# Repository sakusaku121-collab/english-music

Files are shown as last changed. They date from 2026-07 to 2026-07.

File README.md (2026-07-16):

# left-hand-controller

マウスと併用する左手ゲーミングデバイスの自作プロジェクト。
アナログスティック(ホールセンサー)+ メカニカルボタンで、WASD移動をアナログスティックに置き換える。

市販品(Mouserpad v2 等)との差別化ポイント:

- **ダッシュ(Shift)は独立した物理ボタン** — スティックをどれだけ倒してもダッシュは発動しない。
  回復アイテム使用中のレレレ移動・前進でスプリントが暴発してキャンセルされる問題を設計レベルで排除
- **コンテキスト抑制** — 回復キーを押した直後の数秒間はオートダッシュを無効化(オートダッシュをオンにした場合のみ)
- **プロファイル切替** — ゲームごとのキーマップ+スティック挙動を本体フラッシュに保存。どのPCに挿しても同じ挙動
- **筐体はパラメトリック設計** — グリップ角度・ボタン位置を数値で調整して自分の手に合わせられる

## 構成

```
firmware/   Raspberry Pi Pico 用ファームウェア (CircuitPython)
  code.py     メインループ
  config.py   キーマップ・スティック挙動・プロファイル定義(編集するのは基本ここだけ)
hardware/   筐体・部品
  case.scad   パラメトリック筐体モデル (OpenSCAD)
  BOM.md      部品表
docs/
  design-notes.md   設計判断の記録(なぜこの仕様なのか)
```

## 必要なもの

| 部品 | 目安価格 | 備考 |
|---|---|---|
| Raspberry Pi Pico | ~800円 | 無印(有線)。売る前提なので無線モデルは使わない |
| ホールセンサー式スティックモジュール | 500〜1,000円 | PS4/Switch互換の補修部品。アンチドリフト |
| タクトスイッチ or メカニカルスイッチ ×14 | 500〜2,000円 | Kailh choc 推奨(薄型・打鍵感) |
| 配線・M3インサート・ネジ | ~500円 | |
| フィラメント | 試作PLA / 販売版PETG or ASA | 1台あたり100〜150g |

詳細は [hardware/BOM.md](hardware/BOM.md) を参照。

## ファームウェアのセットアップ

1. Pico に [CircuitPython](https://circuitpython.org/board/raspberry_pi_pico/) の UF2 を書き込む
   (BOOTSEL を押しながらUSB接続 → 現れたドライブに UF2 をドラッグ)
2. [Adafruit CircuitPython Bundle](https://circuitpython.org/libraries) から
   `adafruit_hid` フォルダを `CIRCUITPY/lib/` にコピー
3. `firmware/code.py` と `firmware/config.py` を `CIRCUITPY/` 直下にコピー
4. 挿し直すとUSBキーボードとして認識される

## 配線

| 信号 | Picoピン | 備考 |
|---|---|---|
| スティック X軸 | GP26 (ADC0) | |
| スティック Y軸 | GP27 (ADC1) | |
| スティック押し込み | GP11 | C キー |
| 天面ボタン 1/2/3/4 | GP2/GP3/GP4/GP5 | |
| 天面ボタン Q/E/X/F/Tab | GP6/GP7/GP8/GP9/GP10 | |
| 側面ボタン G/Space/Ctrl | GP12/GP13/GP14 | |
| **ダッシュボタン (Shift)** | GP15 | 本プロジェクトの目玉 |
| **ESCボタン** | GP16 | 市販品最大の不満点への対策 |
| 予備ボタン ×2 | GP17/GP18 | 位置・割当は試作で決定 |

ボタンは片側GND、反対側を各GPIOへ(内部プルアップ使用)。
スティックモジュールは VCC→3V3、GND→GND。

USBはPicoのmicroBを直接筐体面に出さず、**パネルマウントUSB-C延長ケーブル**を介して
筐体に固定する(市販品はコネクタ直付け+面一設置が原因で3.5ヶ月破損の報告あり)。

## プロファイル切替

`Tab + スティック押し込み` を1.5秒長押しで次のプロファイルへ切替(選択はフラッシュに保存)。
プロファイルの中身は `firmware/config.py` の `PROFILES` を編集。

## ライセンス

MIT(販売を見据えてクリーンに保つ。外部GPLコードは取り込まない方針)

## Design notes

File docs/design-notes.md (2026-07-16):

# 設計ノート — なぜこの仕様なのか

## 発端

市販の左手デバイス(Mouserpad v2、¥7,590)を検討したが、実際のプレイで致命的な問題があった:

1. **レレレ中のダッシュ暴発**
   Apex のホライゾンで、グラビティリフトで浮きながらバッテリーを巻き、
   弾避けに左右移動(レレレ)を混ぜると、スティックが前方向を含んだ瞬間に
   オートダッシュ(Shift)が乗って回復がキャンセルされる。
2. **前進しながらの回復も不可**
   回復しつつ前に進みたいとき、スティックを倒しすぎるとオートダッシュが
   発動して同じくキャンセル。つまり「回復中はスティックを慎重に倒す」
   ことをプレイヤー側が強いられる。

市販品はこの挙動を変更できない。→ 自作すれば設計レベルで直せる。

## 主要な設計判断

### D1. ダッシュは独立した物理ボタン(デフォルト)

- スティック入力とスプリントを完全に分離する。
  スティックをどれだけ・どの方向に倒しても Shift は乗らない。
- 誤爆源を「賢い制御で抑える」のではなく「構造的に消す」。
  デバッグが楽で、挙動が予測可能。

### D2. オートダッシュはオプションとして残す(比較・他ゲー用)

- プロファイル `auto-dash` で有効化できる。
- ただし市販品との差別化として:
  - **発動閾値を高めに設定可能**(threshold 0.92〜)
  - **コンテキスト抑制**: 回復キー(4)を押した直後 N 秒間は
    オートダッシュを無効化。バッテ5秒/医療キット8秒に合わせて調整。

### D3. プロファイルは本体フラッシュに保存

- `microcontroller.nvm` に選択中インデックスを保存。
- どの PC に挿しても同じ挙動。ドライバ・常駐ソフト不要
  (= 販売時のサポートコストが低い)。

### D4. 有線 USB 固定

- 無線化すると技適(電波法)が必要で個人販売には非現実的。
- 有線 USB バスパワーなら PSE(電気用品安全法)も対象外。

### D5. ファームウェアは完全自作(CircuitPython)

- GPL 系の既製ファームウェアを流用するとソース公開義務が絡む。
  販売を見据えて MIT でクリーンに保つ。
- 挙動の芯(8方向判定、ヒステリシス、抑制ロジック)は 200 行程度で書ける。

### D6. 筐体はオリジナル形状

- Mouserpad v2 の形状をそのまま複製して販売すると
  不正競争防止法(形態模倣、発売から3年)に触れるおそれ。
- どのみち自分の手に合わせてグリップを再設計するので、
  パラメトリックモデル(case.scad)で角度・配置を数値管理する。

## 市販品(Mouserpad v2)レビュー分析 — 弱点と本機での対策

2026-07 時点の Amazon レビューから抽出。★4.1(47件)でもこれだけ不満が残っている
= 改善版を出せば刺さる余地が大きい。

| # | 市販品の弱点(レビューより) | 本機での対策 |
|---|---|---|
| 1 | **ESCキーが無い**。ゲーム内で再割当できず、ゲーム中はPowerToys等も無効。頻繁にキーボードへ手を伸ばす羽目に | **ESC物理ボタンを追加**(config で `top_esc` として定義済み)。キーマップ自由なので任意キーにも変更可 |
| 2 | **キー割当が固定**(変更不可)。左Shift や ESC が割当できずゲームによっては使い物にならない | ファームウェアの config でフルリマップ可能。プロファイル切替も対応済み |
| 3 | **ボタンの押下感がふんわり**、カチッと感なし。強く押さないと反応せず、二度押しでしのぐ人も。分解したら半田不良の個体もあり | メカニカルスイッチ(Kailh choc 等)+ちゃんとした半田付け。試作段階から導通チェックを工程に入れる |
| 4 | **ボタン数が足りない**(押しにくい位置でもいいから3つ増やして欲しいという要望) | 予備ボタン2個分のピンを config に確保(`spare_1`/`spare_2`)。筐体側で増設位置を試作しながら決める |
| 5 | **小指・薬指が窮屈**。ボタン操作しない指で握り続けるため手首の筋が痛む。「親指側を細く、薬指小指側を太く」という具体的提案あり | `case.scad` のグリップを上下で太さ可変に(親指側細め・下側太め)。パラメトリックなので試作で追い込める |
| 6 | **机の手前端で使うと手が浮いて小指側の掌に荷重集中**、痛み・痺れ。ジェルクッションが欲しいという声 | パームレスト部を広めに設計+底面にゲルパッド貼付を標準化。設置姿勢(机上前提)をドキュメント化 |
| 7 | **正面最下段の1・2ボタンが握りを浮かせないと届かない**=ほぼ死にボタン | ボタン配置は`button_layout`で座標管理。届かない位置には置かない。試作で親指可動域を実測してから確定 |
| 8 | **スティックがシビア**。少し倒しただけで全開扱い、歩ける範囲が1mm程度。乗り物操縦では曲がりすぎる。オートダッシュ常時発動で余計に酷い | デッドゾーン・発動閾値を config で調整可能。オートダッシュはデフォルトOFF+コンテキスト抑制。将来的にはゲームパッド軸出力プロファイルも検討(ロードマップ参照) |
| 9 | **MicroUSBコネクタが3.5ヶ月で破損**(役立った47人=最重要レビュー)。基板を筐体と面一に置いたせいでコネクタ金属部が露出し、奥まで挿そうとグリグリやって壊れる | **コネクタを筐体内に沈めない設計ミスを回避**: Pico本体は内部固定し、パネルマウントUSB-C延長ケーブルで筐体面に出す。ストレインリリーフ付き。修理性も上がる |
| 10 | **スティックの首回り強度が弱い**、2週間で擦れ粉 | ホールセンサー式の交換モジュール前提。開口部エッジを面取りし、モジュール交換をネジ止め式に |
| 11 | 背面の交換パーツが付属するが**説明書に一切記載なし** | 説明書(README)に全付属品と用途を明記。販売時はここが信頼の差になる |

レビュー全体の温度感: 「コンセプトは唯一無二、品質は値段なり、改善版を出してくれ」。
つまり**市場は改善版を待っている**。AZERON Cyborg(高価格帯)との間に価格帯の空白もある。

## 販売までのロードマップ

1. **自分用1号機**: PLA試作でグリップ形状を確定 → PETG で常用機
2. **公開**: SNS で反応を見る(写真+ダッシュ分離のデモ動画)
3. **販売版設計**: QC しやすい分割、キーキャップ色替えでカラバリ、
   Raspberry Pi 財団の VID/PID 割当を申請
4. **販路**: BOOTH から開始 → 反応次第で Makuake 等のクラファン

## 未解決・要検証

- [ ] スティックモジュールの ADC 実効レンジ実測(HALF_RANGE の補正)
- [ ] グリップ角度の最適値(grip_angle 24/28/32° で試作予定)
- [ ] Kailh choc 化した場合の天面プレート厚と穴形状
- [ ] 回復キー抑制のデフォルト秒数(バッテ運用なら 5.5s が適正かも)
- [ ] USB ポーリングレートの実測(CircuitPython の HID は実測で確認する)
- [ ] ゲームパッド軸出力プロファイル(乗り物操縦対策。キーボード8方向では原理的に
      アナログ操作にならないため、XInput/DirectInput 軸として出すモードを検討)
- [ ] パネルマウント USB-C 延長ケーブルの選定(レビュー#9 のコネクタ破損対策)
- [ ] spare_1 / spare_2 の実装位置(押しにくくてもいいから欲しい、というレビュー要望)

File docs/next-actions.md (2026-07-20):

# ネクストアクション

進捗はチェックボックスで管理。詳細な理由は design-notes.md、価格の目安は shopping-list.md 参照。

> **状況 (2026-07-19)**: プリンター+フィラメント到着済み(前倒し)。初期セットアップ中。
> グリップ試作STL(24/28/32°)は `hardware/stl/` に生成済み。
> **フェーズ1電子部品と収納・工具はまだ未発注 ← 最優先。**

## ✅ 済み

- [x] プリンター選定・購入(A1 mini ¥26,000 セール)
- [x] フィラメント購入(PLA黒・PETG黒 各1kg スプール付き)+予備ホットエンド
- [x] ファームウェア骨格・筐体パラメトリックモデル・競合レビュー分析
- [x] グリップ試作STL生成(24°/28°/32°)

## 🔄 いま

- [ ] **1. A1 mini 初期セットアップ**(30〜45分)
      保護材外し → ウィザード → 自動キャリブレーション → PLA装填 → サンプル印刷
- [ ] **2. Bambu Studio をPCにインストール** → `grip_test_28deg.stl` を印刷(サポート自動ON)

## 🛒 発注する(未発注・最優先)

### 電子部品

| 品名 | おすすめ購入先 | 備考 |
|---|---|---|
| Raspberry Pi Pico(無印・ピンヘッダ実装済み) | **秋月電子通商**(akizukidenshi.com) | 通販コード検索「Pico H」。〜¥1,000 |
| ホールセンサースティックモジュール ×2 | **Amazon** | 検索「ホールエフェクト ジョイスティック PS4 交換」。「Hall Effect」明記の物のみ |
| タクトスイッチ 6mm ×20 | **秋月電子** | Picoと同時注文で送料節約 |
| ブレッドボード+ジャンパワイヤセット | **秋月電子** or Amazon(ELEGOO等) | |
| 耐熱電子ワイヤ AWG28 | **秋月電子** | |
| 静電気防止袋 | **Amazon** | |

### 工具(持ってなければ)

| 品名 | おすすめ購入先 | 備考 |
|---|---|---|
| はんだごて HAKKO FX-600 | **Amazon** or ヨドバシ | 偽物注意、販売元をよく確認 |
| はんだ・こて台 | 同上 | |
| ニッパー・ワイヤーストリッパー | **Amazon** or ホームセンター | |
| テスター | **Amazon** | 2,000円以下ので十分 |
| デジタルノギス | **Amazon**(シンワ測定が定番) | |

### 収納・管理

| 品名 | おすすめ購入先 | 備考 |
|---|---|---|
| トランク型工具箱(TRUSCO T-350等) | **Amazon** or **モノタロウ** | 内寸35cm以上 |
| 仕切り可動パーツケース ×2(リングスター スーパーピッチ) | **Amazon** or ホームセンター | |
| 耐熱シリコン作業マット | **Amazon** | |
| フィラメント防湿: 6L級密閉容器 ×2+シリカゲル+湿度計 | 容器は**ニトリ/ホームセンター**、乾燥剤・湿度計は**Amazon** | SUNLUドライボックス(Amazon)でも可 |
| M3ヒートインサート・M3×8皿ネジ | **Amazon**(uxcell等) or **モノタロウ** | v1筐体で使用 |

**発注のコツ**: 秋月でまとめて1回+Amazonでまとめて1回の計2注文に集約すると送料と手間が最小。

## ⬜ 印刷とグリップ確定(電子部品なしで進む)

- [ ] **3. grip_test_28deg.stl を印刷** → 握った感想+写真を共有
- [ ] **4. 24°/32°も印刷して比較** → 角度確定
- [ ] **5. 太さ・付け根・天面の微調整版を印刷**(必要なら数回転)
- [ ] **6. 親指可動域を実測 → ボタン配置(button_layout)確定**

## ⬜ 電子部品が届いたら

- [ ] **7. PicoにCircuitPython導入 → ブレッドボード仮組み**
- [ ] **8. ファームウェア書き込み+スティックADC実測合わせ**(Claudeと一緒に)
- [ ] **9. メモ帳とApex射撃訓練場で入力確認**

## ⬜ 形が決まったら

- [ ] **10. v1筐体設計**(内部空洞・基板マウント・底蓋・パネルマウントUSB-C口)
- [ ] **11. はんだ付け本組み → 動作確認**
- [ ] **12. PETGで常用機を印刷して移行**
- [ ] **13. Apex実戦投入 → config煮詰め**(バッテ巻きレレレが快適になったら勝ち)

## ⬜ 売る気になったら

- [ ] **14. SNSに写真+デモ動画投稿 → 反応を見る**
- [ ] **15. 反応があれば販売版設計へ**(design-notes.md のロードマップ参照)

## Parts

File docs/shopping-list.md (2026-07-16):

# 買い物リスト

段階別。フェーズ1はプリンター到着前でも進められる(ブレッドボードでファームウェア検証)。

> **状況 (2026-07-16)**: プリンター本体+フィラメント2巻+予備ホットエンドを注文済(計¥31,498)。
> 発送予定 7/23頃。**到着までにフェーズ1(電子部品)とフェーズ2の残り(ネジ・インサート・防湿箱)を発注しておくこと。**

## フェーズ1: 電子工作(今すぐ買ってOK) — 約6,000〜9,000円

| ✓ | 品名 | 数量 | 目安価格 | 入手先 | メモ |
|---|---|---|---|---|---|
| ☐ | Raspberry Pi Pico(無印) | 1 | 800円 | 秋月電子 / スイッチサイエンス | ピンヘッダ実装済み版が楽(+200円)。**W(無線)ではなく無印** |
| ☐ | ホールセンサー式スティックモジュール | 2 | 1,000〜2,000円 | Amazon「ホールエフェクト ジョイスティック 補修 PS4」 | **予備込みで2個**。押し込みスイッチ付きを選ぶ |
| ☐ | タクトスイッチ 6mm | 20 | 300円 | 秋月電子 | 14個使用+予備 |
| ☐ | ブレッドボード + ジャンパワイヤ(オスオス/オスメス) | 1式 | 800円 | 秋月電子 / Amazon | プリンター到着前のファームウェア検証用 |
| ☐ | 耐熱電子ワイヤ AWG28(数色) | 1式 | 500円 | 秋月電子 | 本組み用 |
| ☐ | USBケーブル microB(データ通信対応) | 1 | 300〜500円 | | **充電専用ケーブル不可**。手持ちがあれば省略 |
| ☐ | はんだごてセット(温調式) | 1 | 2,000〜4,000円 | Amazon(HAKKO FX-600 なら4,000円前後) | 手持ちがあれば省略 |
| ☐ | はんだ(鉛フリー or 共晶 0.8mm) | 1 | 500円 | | |
| ☐ | ニッパー・ワイヤーストリッパー | 1式 | 1,000円 | | 手持ちがあれば省略 |
| ☐ | テスター(導通チェックができれば安物で可) | 1 | 1,000〜2,000円 | | 配線ミス調査に必須。手持ちがあれば省略 |

## 収納・管理(フェーズ1と一緒に買う) — 約4,000〜5,500円

方針: **「工具箱ひとつにプロジェクト全部が入る」状態**にする。小物は仕切りケースに分類し、
その仕切りケースごと大きい工具箱に収まるサイズで選ぶ。

| ✓ | 品名 | 数量 | 目安価格 | 入手先 | メモ |
|---|---|---|---|---|---|
| ☐ | トランク型工具箱(内寸 幅350mm以上) | 1 | 2,000〜3,000円 | TRUSCO トランクツールボックス T-350 / アイリスオーヤマ ハードケース | **これが「全部入る」母艦**。はんだごて・工具・下記の仕切りケース2個が丸ごと入るサイズを確認して買う |
| ☐ | 仕切り可動式パーツケース(小) | 2 | 600〜900円/個 | リングスター スーパーピッチ SP-3000 / SK11 パーツケース | 1個目: スイッチ・スティック・Pico等の電子部品用。2個目: ネジ・インサート・ゴム足等の機構部品用。仕切りが「可動式」のものを選ぶ(固定仕切りは後で必ず困る) |
| ☐ | 静電気防止袋(帯電防止ジップ袋) | 10枚 | 300円 | Amazon | Picoと基板の保管用。パーツケースに入れる前にこれに入れる |
| ☐ | 耐熱シリコン作業マット | 1 | 1,000〜1,500円 | Amazon「はんだ付け 作業マット」 | 机の保護+ネジ小物の迷子防止(縁とポケット付き)。丸めれば工具箱に入る |
| ☐ | はんだごて台 | 1 | 700〜1,000円 | HAKKO 633系 | ごてセットに付属していれば省略。安全に直結するのでケチらない |

## フェーズ2: 3Dプリンター(決心がついたら) — 約38,000〜50,000円

| ✓ | 品名 | 数量 | 目安価格 | メモ |
|---|---|---|---|---|
| ☑ | Bambu Lab A1 mini | 1 | **¥26,000 購入済** | 2026-07-16 Bambu公式周年セールで注文。発送予定 7/23頃 |
| ☑ | PLA フィラメント(試作用) | 1kg | **¥2,210 購入済** | Bambu PLA ベーシック ブラック(10101)/ スプール付き。次回からリフィルでOK |
| ☑ | PETG フィラメント(常用機) | 1kg | **¥1,885 購入済** | Bambu PETG ベーシック ブラック(30105)/ スプール付き。次回からリフィルでOK |
| ☑ | ホットエンド予備 0.4mm ステンレス | 1 | **¥1,403 購入済** | 同時購入割引で確保。詰まり時の即時交換用 |
| ☐ | M3 ヒートインサート(M3×5×4程度) | 20個 | 500円 | Amazon。底蓋固定用 |
| ☐ | M3×8mm 皿ネジ | 20本 | 300円 | |
| ☐ | ヒートインサート用こて先(M3) | 1 | 1,000円 | あると圧入が真っ直ぐ決まる。無くても可 |
| ☐ | 滑り止めゴム足 | 1袋 | 300円 | |
| ☐ | フィラメント防湿ボックス + 乾燥剤 | 2式 | 1,500〜3,000円 | 密閉クリアボックス(1kgスプールが入る6L級)+ シリカゲル + 湿度計。既製品なら SUNLU ドライボックス。**フィラメントの数だけ必要**(PLA用とPETG用で2つ) |
| ☐ | ノギス(デジタル) | 1 | 1,500〜2,500円 | 筐体の寸法合わせ・スティックモジュール実測に必須。工具箱に入るサイズ |

## フェーズ3: 販売版を作る段階で(まだ買わない)

| ✓ | 品名 | 目安価格 | メモ |
|---|---|---|---|
| ☐ | Kailh choc v1 スイッチ + キーキャップ | 打鍵感の差別化。遊舎工房で試打してから選ぶ | |
| ☐ | ASA フィラメント | 3,000〜4,000円/kg | 耐熱・耐候。販売版筐体用 |
| ☐ | AMS lite(多色ユニット) | 30,000円前後 | ツートン展開したくなったら |
| ☐ | USBケーブル(製品同梱用)まとめ買い | | |
| ☐ | 梱包材(箱・緩衝材) | | BOOTH発送用 |

## 合計目安

- **フェーズ1+収納**(工具持ちなら): 約7,000〜9,500円
- **フェーズ1+収納+2**(工具込みフルセット): 約50,000〜60,000円

収納を先に整えておくと、部品が届いた瞬間から「どこに何があるか分かる」状態で始められる。
あとから買うと、散らかった机を片付けるための出費になる(体験談的にみんなそうなる)。

## 買う前の注意

- スティックモジュールは商品ページに「ホールセンサー」「Hall Effect」と明記があるものを。
  無印の互換スティック(可変抵抗式)はドリフトするので買わない
- Pico は技適の絡みで **Pico W を買わないこと**(無線を使わなくても割高なだけ)
- フィラメントは開封後に吸湿するので、乾燥剤入りの密閉袋かボックスも100均で調達しておくと良い

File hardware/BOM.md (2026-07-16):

# 部品表 (BOM)

試作1台分。価格は2026年時点の目安。

## 電子部品

| # | 部品 | 数量 | 目安価格 | 入手先の例 | 備考 |
|---|---|---|---|---|---|
| 1 | Raspberry Pi Pico(無印・ピンヘッダなし) | 1 | ~800円 | 秋月電子、スイッチサイエンス | 販売を見据えて**有線モデル固定**(無線は技適が必要になる) |
| 2 | ホールセンサー式アナログスティックモジュール | 1 | 500〜1,000円 | Amazon「ホールエフェクト ジョイスティック 補修 PS4」 | アンチドリフトの要。押し込みスイッチ付きを選ぶ |
| 3 | タクトスイッチ(6mm) | 14 | ~300円 | 秋月電子 | 試作用。販売版は Kailh choc v1 等に置換予定 |
| 4 | 耐熱電子ワイヤ AWG28 | 適量 | ~300円 | | |
| 5 | USBケーブル(microB、データ通信対応) | 1 | ~300円 | | Pico 無印は microB |

## 機構部品

| # | 部品 | 数量 | 目安価格 | 備考 |
|---|---|---|---|---|
| 6 | M3 ヒートインサート | 4〜6 | ~200円 | 底蓋固定用 |
| 7 | M3 × 8mm 皿ネジ | 4〜6 | ~100円 | |
| 8 | 滑り止めゴム足 | 4 | ~100円 | |

## フィラメント

| 用途 | 材料 | 使用量目安 |
|---|---|---|
| 試作(形状検討) | PLA | 1回 80〜120g × 反復回数 |
| 完成版・販売版 | PETG または ASA | 100〜150g/台 |

PLA は長時間の握り込みと夏場の温度でクリープ変形するため、常用・販売には使わない。

## 合計目安

電子部品+機構部品で **約2,500〜3,000円/台**(フィラメント除く)。

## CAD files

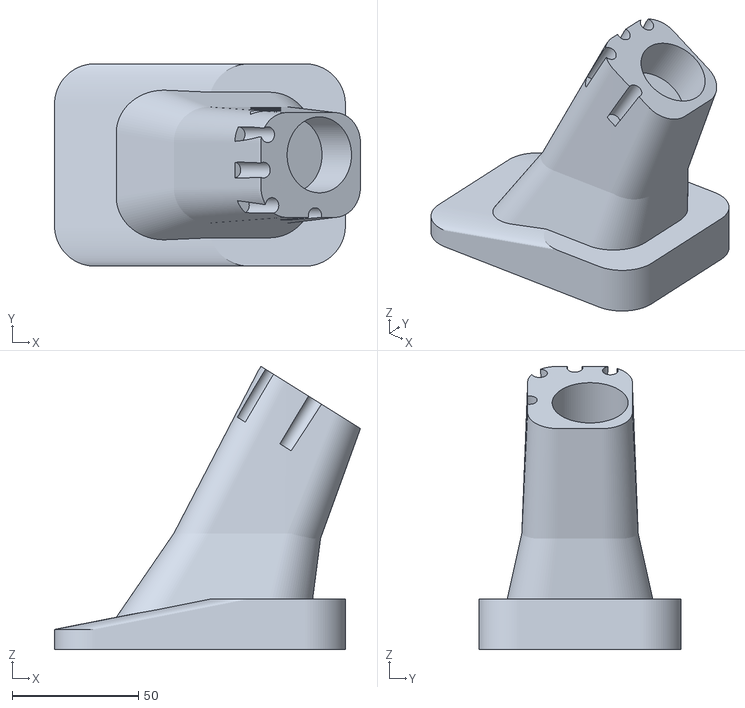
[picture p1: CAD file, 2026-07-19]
hardware/stl/grip_test_24deg.stl
121.0 x 80.0 x 112.0

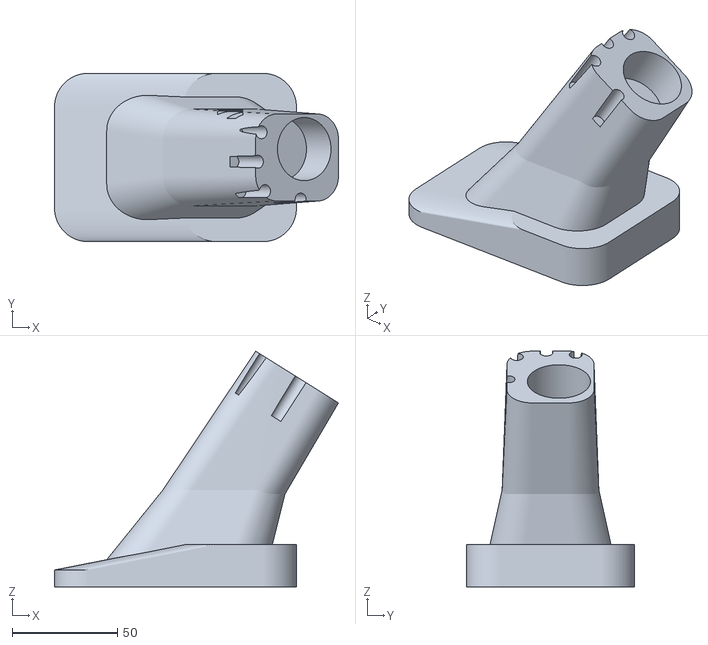
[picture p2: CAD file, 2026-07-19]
hardware/stl/grip_test_32deg.stl
135.0 x 80.0 x 112.0

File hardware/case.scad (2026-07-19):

// =============================================================
// left-hand-controller パラメトリック筐体 v0 (OpenSCAD)
//
// これはエルゴノミクス試作用の「たたき台」。
// 上部のパラメータを変えて印刷 → 握る → 調整、を繰り返す前提。
// 印刷時は $fn を上げる(プレビューは低くて可)。
// =============================================================

// ---- 全体 ----
$fn = 48;            // 曲面分割数(印刷時は 96 以上推奨)
wall = 2.4;          // 壁厚

// ---- ベース(手首を乗せる傾斜土台) ----
// 平板ではなく、手首側が低くグリップ付け根側が高いスロープ。
// 掌の腹をこの斜面で受けて、机の縁での「手が浮く」問題(レビュー#6)も緩和する
base_len          = 115;  // 前後長
base_width        = 80;   // 左右幅
base_height_rear  = 8;    // 手首側の高さ(低い)
base_height_front = 20;   // グリップ付け根側の高さ(高い)

// ---- グリップ(握り柱) ----
grip_angle  = 28;    // 前傾角度(度)。ここが握り心地の最重要パラメータ
grip_height = 78;    // 柱の高さ
grip_width  = 46;    // 柱の左右幅
grip_depth  = 58;    // 柱の前後厚
grip_offset_y = 8;   // ベース上での前後位置(+で高い側=前寄り)
grip_root_h   = 24;  // 付け根ブレンド部の高さ(掌の腹の横が当たる裾広がり)

// ---- 天面ボタンプレート ----
plate_tilt   = 32;   // 天面の傾き(度)。親指が自然に届く角度に合わせる
plate_width  = 52;
plate_length = 72;

// ---- スティック ----
stick_hole_d   = 30;  // スティック可動部の開口径
stick_mount_w  = 34;  // モジュール基板の取付間隔(実測して合わせる)

// ---- ボタン穴 ----
btn_hole = 6.2;       // タクトスイッチキャップ径+クリアランス
                      // Kailh choc なら 13.8x13.8 の角穴に変更する

// ---- 側面ボタン(G / Space / Ctrl) ----
side_btn_w = 12;
side_btn_h = 6;
side_btn_pitch = 16;

// =============================================================

// 天面のボタン配置(プレートローカル座標 [x, y])
// 実機写真を参考にした扇状配置。自分の親指の可動域に合わせて調整する
button_layout = [
    [-16,  26],  // 3
    [ -4,  30],  // 4
    [  8,  26],  // Tab
    [-20,  12],  // F
    [-22,  -2],  // Q
    [-18, -16],  // E
    [  2, -20],  // X
    [-12, -28],  // 1
    [  0, -32],  // 2
];
stick_pos = [4, 4];  // スティック中心(プレートローカル)

module rounded_slab(l, w, h, r) {
    hull()
        for (dx = [-1, 1], dy = [-1, 1])
            translate([dx * (l/2 - r), dy * (w/2 - r), 0])
                cylinder(h = h, r = r);
}

// 手首側の傾斜土台(後端の低い断面と前端の高い断面を hull で繋いだスロープ)
module base() {
    hull() {
        translate([-base_len / 2 + 27, 0, 0])
            rounded_slab(54, base_width, base_height_rear, 16);
        translate([base_len / 2 - 27, 0, 0])
            rounded_slab(54, base_width, base_height_front, 16);
    }
}

// 前傾した握り柱。2段構成:
//  1) 付け根ブレンド: 裾広がりのスカートで土台に滑らかに接続し、
//     掌の腹の横が当たる面を作る
//  2) 握り柱本体: 上端断面は plate_tilt で傾けてあり、
//     hull の天面がそのままボタンプレートになる
module grip() {
    top_shift = grip_height * tan(grip_angle);
    mid_shift = grip_root_h * tan(grip_angle);
    union() {
        hull() {
            translate([grip_offset_y - 4, 0, base_height_front - 12])
                rounded_slab(grip_depth + 20, grip_width + 16, 2, 18);
            translate([grip_offset_y + mid_shift, 0, base_height_front + grip_root_h])
                rounded_slab(grip_depth, grip_width, 2, 14);
        }
        hull() {
            translate([grip_offset_y + mid_shift, 0, base_height_front + grip_root_h])
                rounded_slab(grip_depth, grip_width, 2, 14);
            translate([grip_offset_y + top_shift, 0, base_height_front + grip_height])
                rotate([0, plate_tilt, 0])
                    rounded_slab(grip_depth * 0.8, grip_width * 0.9, 2, 12);
        }
    }
}

// 天面プレートの座標系へ移動(grip() の上端断面と同じ変換)
module on_plate() {
    top_shift = grip_height * tan(grip_angle);
    translate([grip_offset_y + top_shift, 0, base_height_front + grip_height])
        rotate([0, plate_tilt, 0])
            children();
}

// スティック開口+ボタン穴
module top_cutouts() {
    on_plate() {
        translate([stick_pos[0], stick_pos[1], -20])
            cylinder(h = 40, d = stick_hole_d);
        for (p = button_layout)
            translate([p[0], p[1], -20])
                cylinder(h = 40, d = btn_hole);
    }
}

// 側面ボタンの角穴(小指側の面)
module side_cutouts() {
    for (i = [0 : 2])
        translate([grip_offset_y + 12,
                   grip_width / 2 - wall - 2,
                   base_height_front + grip_root_h + 8 + i * side_btn_pitch])
            cube([side_btn_w, wall + 6, side_btn_h]);
}

// ---- 本体 ----
// 現段階はソリッド(軽量化はスライサーのインフィル設定に任せる)。
// 基板・配線用の内部空間と底蓋は、グリップ形状確定後の v1 で設計する
difference() {
    union() {
        base();
        grip();
    }
    top_cutouts();
    side_cutouts();
}

// TODO(v1 以降):
// - 底蓋 + M3インサートボス
// - スティックモジュールの取付ボス(stick_mount_w で位置決め)
// - Kailh choc 用の角穴プレートへの差し替え
// - パネルマウントUSB-C口の開口(レビュー分析#9: 直付け面一コネクタは破損する)
//
// レビュー分析(docs/design-notes.md)からの形状要件:
// - グリップ太さを上下で変える: 親指側(側面ボタン付近)は細く、
//   薬指・小指側(下部)は太く → 握り込む力を減らして手首痛対策 (#5)
// - パームレスト部(base)を広めに取り、掌の小指側エッジに角を当てない (#6)
// - ボタンは親指可動域の実測範囲内のみに配置。届かない位置に置かない (#7)
// - ESC + 予備2ボタンの配置スペースを天面外周に確保 (#1, #4)
// - スティック開口部エッジは面取りし、モジュールはネジ止めで交換可能に (#10)

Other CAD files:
hardware/stl/grip_test_28deg.stl

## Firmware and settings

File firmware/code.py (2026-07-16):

# =============================================================
# left-hand-controller ファームウェア (CircuitPython / Raspberry Pi Pico)
#
# アナログスティック → WASD 8方向キー入力
# ボタン → 任意キー(config.py のプロファイルで定義)
# ダッシュは独立ボタン。オートダッシュはオプション+コンテキスト抑制付き。
# =============================================================
import math
import time

import analogio
import keypad
import microcontroller
import usb_hid
from adafruit_hid.keyboard import Keyboard

import config

# --- 初期化 -------------------------------------------------------
keyboard = Keyboard(usb_hid.devices)

stick_x = analogio.AnalogIn(config.PIN_STICK_X)
stick_y = analogio.AnalogIn(config.PIN_STICK_Y)

button_names = list(config.BUTTON_PINS.keys())
keys = keypad.Keys(
    [config.BUTTON_PINS[n] for n in button_names],
    value_when_pressed=False,  # 内部プルアップ、GNDに落として押下
    pull=True,
)

# 起動時にスティックが中立である前提でセンターを実測
# (組み立て後の個体差・ホールセンサーのオフセットを吸収する)
def read_raw():
    x = stick_x.value
    y = stick_y.value
    return x, y


def calibrate_center(samples=64):
    sx = sy = 0
    for _ in range(samples):
        x, y = read_raw()
        sx += x
        sy += y
        time.sleep(0.002)
    return sx // samples, sy // samples


CENTER_X, CENTER_Y = calibrate_center()
HALF_RANGE = 32768  # 16bit ADC の中心からの振れ幅の目安


def read_stick():
    """スティックの倒し量を (-1.0〜1.0, -1.0〜1.0) で返す。上が +y。"""
    rx, ry = read_raw()
    x = (rx - CENTER_X) / HALF_RANGE
    y = (ry - CENTER_Y) / HALF_RANGE
    if config.STICK_INVERT_X:
        x = -x
    if config.STICK_INVERT_Y:
        y = -y
    # 端で1.0を超えることがあるのでクランプ
    return max(-1.0, min(1.0, x)), max(-1.0, min(1.0, y))


# --- プロファイル管理 ---------------------------------------------
def load_profile_index():
    idx = microcontroller.nvm[0]
    if idx >= len(config.PROFILES):
        idx = 0
    return idx


def save_profile_index(idx):
    microcontroller.nvm[0] = idx


profile_index = load_profile_index()
profile = config.PROFILES[profile_index]


def blink_profile(idx):
    """プロファイル番号を LED の点滅回数で通知(Pico 内蔵LED)。"""
    try:
        import board
        import digitalio

        led = digitalio.DigitalInOut(board.LED)
        led.direction = digitalio.Direction.OUTPUT
        for _ in range(idx + 1):
            led.value = True
            time.sleep(0.12)
            led.value = False
            time.sleep(0.12)
        led.deinit()
    except Exception:
        pass  # LEDが使えない環境でも動作は継続


# --- 8方向セクター定義 --------------------------------------------
# 角度0° = 右、反時計回り。45°ごとの8セクター(境界は22.5°)
SECTOR_KEYS = [
    ("move_right",),
    ("move_right", "move_up"),
    ("move_up",),
    ("move_up", "move_left"),
    ("move_left",),
    ("move_left", "move_down"),
    ("move_down",),
    ("move_down", "move_right"),
]


def stick_direction_keys(x, y, active, cfg):
    """現在押すべき移動キーの論理名 set と、新しい active 状態を返す。

    ヒステリシス: 一度倒したと判定したら、deadzone - release_margin を
    下回るまで解除しない(境界でのチャタリング防止)。
    """
    magnitude = math.sqrt(x * x + y * y)
    press_th = cfg["deadzone"]
    release_th = cfg["deadzone"] - cfg["release_margin"]

    if active:
        if magnitude < release_th:
            return set(), False
    else:
        if magnitude < press_th:
            return set(), False

    angle = math.degrees(math.atan2(y, x))  # -180〜180
    sector = int(((angle + 22.5) % 360) // 45)
    return set(SECTOR_KEYS[sector]), True


# --- メインループ -------------------------------------------------
pressed_buttons = set()      # 押下中の物理ボタン(論理名)
pressed_move_keys = set()    # 押下中の移動キー(論理名)
stick_active = False
auto_dash_on = False
suppress_until = 0.0         # この時刻までオートダッシュ禁止
combo_since = None           # プロファイル切替コンボの押下開始時刻

blink_profile(profile_index)


def set_key(logical_name, pressed):
    """論理名 → 現プロファイルのキーコードで押下/解放。"""
    keycode = profile["keymap"].get(logical_name)
    if keycode is None:
        return
    if pressed:
        keyboard.press(keycode)
    else:
        keyboard.release(keycode)


while True:
    now = time.monotonic()

    # ---- ボタンイベント処理 ----
    event = keys.events.get()
    while event is not None:
        name = button_names[event.key_number]
        if event.pressed:
            pressed_buttons.add(name)
            set_key(name, True)
            # 回復キー等が押されたらオートダッシュを一定時間抑制
            ad = profile["auto_dash"]
            if name in ad["suppress_after"]:
                suppress_until = now + ad["suppress_seconds"]
        else:
            pressed_buttons.discard(name)
            set_key(name, False)
        event = keys.events.get()

    # ---- プロファイル切替コンボ ----
    if all(n in pressed_buttons for n in config.PROFILE_SWITCH_COMBO):
        if combo_since is None:
            combo_since = now
        elif now - combo_since >= config.PROFILE_SWITCH_HOLD_SEC:
            # 全キー解放してからプロファイルを進める
            keyboard.release_all()
            pressed_move_keys = set()
            stick_active = False
            auto_dash_on = False
            profile_index = (profile_index + 1) % len(config.PROFILES)
            profile = config.PROFILES[profile_index]
            save_profile_index(profile_index)
            blink_profile(profile_index)
            combo_since = None
    else:
        combo_since = None

    # ---- スティック → 移動キー ----
    x, y = read_stick()
    want_keys, stick_active = stick_direction_keys(
        x, y, stick_active, profile["stick"]
    )

    for name in want_keys - pressed_move_keys:
        set_key(name, True)
    for name in pressed_move_keys - want_keys:
        set_key(name, False)
    pressed_move_keys = want_keys

    # ---- オートダッシュ(オプション) ----
    ad = profile["auto_dash"]
    if ad["enabled"]:
        magnitude = math.sqrt(x * x + y * y)
        want_dash = (
            magnitude >= ad["threshold"]
            and now >= suppress_until
            and (not ad["forward_only"] or "move_up" in pressed_move_keys)
        )
        if want_dash and not auto_dash_on:
            set_key("dash", True)
            auto_dash_on = True
        elif not want_dash and auto_dash_on:
            # 物理ダッシュボタンを握っている間は離さない
            if "dash" not in pressed_buttons:
                set_key("dash", False)
            auto_dash_on = False

    time.sleep(0.001)  # ~1kHz ポーリング

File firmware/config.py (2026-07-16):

# =============================================================
# left-hand-controller 設定ファイル
# 挙動を変えたいときは基本このファイルだけを編集する。
# =============================================================
import board
from adafruit_hid.keycode import Keycode

# --- ピン割り当て -------------------------------------------------
# スティック(アナログ)
PIN_STICK_X = board.GP26  # ADC0
PIN_STICK_Y = board.GP27  # ADC1

# スティックの向き調整(組み付け方向に合わせて反転)
STICK_INVERT_X = False
STICK_INVERT_Y = True  # 多くのモジュールは上に倒すとADC値が下がる

# ボタン: 論理名 → GPIO
# 論理名はプロファイルのキーマップから参照される
BUTTON_PINS = {
    "top_1": board.GP2,
    "top_2": board.GP3,
    "top_3": board.GP4,
    "top_4": board.GP5,
    "top_q": board.GP6,
    "top_e": board.GP7,
    "top_x": board.GP8,
    "top_f": board.GP9,
    "top_tab": board.GP10,
    "stick_click": board.GP11,
    "side_g": board.GP12,
    "side_space": board.GP13,
    "side_ctrl": board.GP14,
    "dash": board.GP15,  # 独立ダッシュボタン
    # --- 市販品レビュー分析(design-notes #1, #4)対応 ---
    "top_esc": board.GP16,  # ESC物理ボタン。市販品最大の不満点
    "spare_1": board.GP17,  # 増設用。位置・キーは試作しながら決める
    "spare_2": board.GP18,  # 増設用
}

# --- プロファイル切替 ---------------------------------------------
# この2ボタンを同時に長押しすると次のプロファイルへ
PROFILE_SWITCH_COMBO = ("top_tab", "stick_click")
PROFILE_SWITCH_HOLD_SEC = 1.5

# --- プロファイル定義 ---------------------------------------------
# stick:
#   deadzone        : 中心の不感帯 (0.0-1.0)。これ未満の倒しは無視
#   release_margin  : チャタリング防止のヒステリシス幅
# auto_dash:
#   enabled          : True にするとスティックの倒し込みで Shift が乗る(市販品互換モード)
#   threshold        : オートダッシュが発動する倒し量 (0.0-1.0)。高いほど暴発しにくい
#   forward_only     : True なら前方向(上)を含むときだけ発動
#   suppress_after   : ここに挙げたボタンを押した直後はオートダッシュを無効化
#   suppress_seconds : 無効化の持続秒数(バッテ=5秒, 医療キット=8秒 に合わせて調整)
PROFILES = [
    {
        # Apex(ホライゾン運用)想定:
        # オートダッシュは切り、ダッシュは物理ボタンのみ。
        # 回復中にスティックをどう倒してもキャンセルされない。
        "name": "apex",
        "keymap": {
            "move_up": Keycode.W,
            "move_down": Keycode.S,
            "move_left": Keycode.A,
            "move_right": Keycode.D,
            "top_1": Keycode.ONE,
            "top_2": Keycode.TWO,
            "top_3": Keycode.THREE,
            "top_4": Keycode.FOUR,
            "top_q": Keycode.Q,
            "top_e": Keycode.E,
            "top_x": Keycode.X,
            "top_f": Keycode.F,
            "top_tab": Keycode.TAB,
            "stick_click": Keycode.C,
            "side_g": Keycode.G,
            "side_space": Keycode.SPACE,
            "side_ctrl": Keycode.LEFT_CONTROL,
            "dash": Keycode.LEFT_SHIFT,
            "top_esc": Keycode.ESCAPE,
            # spare_1 / spare_2 は未割当(押しても何も起きない)。
            # 使うことになったらここに追記する。
        },
        "stick": {
            "deadzone": 0.30,
            "release_margin": 0.05,
        },
        "auto_dash": {
            "enabled": False,
            "threshold": 0.95,
            "forward_only": True,
            "suppress_after": ["top_4"],  # 回復キー
            "suppress_seconds": 7.0,
        },
    },
    {
        # 市販品互換モード: オートダッシュあり(比較・検証用)。
        # ただし threshold を高めにして、回復キー後は抑制する。
        "name": "auto-dash",
        "keymap": {
            "move_up": Keycode.W,
            "move_down": Keycode.S,
            "move_left": Keycode.A,
            "move_right": Keycode.D,
            "top_1": Keycode.ONE,
            "top_2": Keycode.TWO,
            "top_3": Keycode.THREE,
            "top_4": Keycode.FOUR,
            "top_q": Keycode.Q,
            "top_e": Keycode.E,
            "top_x": Keycode.X,
            "top_f": Keycode.F,
            "top_tab": Keycode.TAB,
            "stick_click": Keycode.C,
            "side_g": Keycode.G,
            "side_space": Keycode.SPACE,
            "side_ctrl": Keycode.LEFT_CONTROL,
            "dash": Keycode.LEFT_SHIFT,
            "top_esc": Keycode.ESCAPE,
        },
        "stick": {
            "deadzone": 0.30,
            "release_margin": 0.05,
        },
        "auto_dash": {
            "enabled": True,
            "threshold": 0.92,
            "forward_only": True,
            "suppress_after": ["top_4"],
            "suppress_seconds": 7.0,
        },
    },
]

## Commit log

2026-06-10 🎵 Update phrase learning app
2026-07-16 Add left-hand-controller project: firmware, parametric case, BOM, design notes
    - CircuitPython firmware: analog stick to 8-way WASD with hysteresis,
    independent dash button, optional auto-dash with context suppression
    (disables sprint for N seconds after the heal key), flash-persisted
    profiles switched via Tab + stick-click hold
    - Parametric OpenSCAD case skeleton (grip angle / plate tilt / button
    layout as tunable parameters)
    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
    [case.scad]
2026-07-16 Add phased shopping list (electronics now, printer next, sales-stage later)
    Claude-Session: https://claude.ai/code/session_01ThzuGXK6S7NqYLh6Nf2WKa
2026-07-16 Mark printer, filaments, and spare hotend as purchased (Bambu sale 2026-07-16)
    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
2026-07-16 Incorporate competitor review analysis: ESC button, spare buttons, USB-C panel mount, ergonomic requirements
    11 weaknesses extracted from Mouserpad v2 Amazon reviews, each mapped
    to a countermeasure: dedicated ESC key (top complaint), full remapping,
    mechanical switches, grip thickness balance, palm-rest load, reachable
    button layout, tunable stick thresholds, recessed panel-mount USB-C
    (flush micro-USB broke at 3.5 months in the field), and documented
    accessories.
    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
    [case.scad]
2026-07-19 Fix case model (solid body, tilted top plate), add grip test STLs at 24/28/32 degrees
    The previous shell-subtraction cut away the top face; the body is now
    solid (slicer infill handles weight) and the grip's top section is
    rotated by plate_tilt so the thumb plate angle is real. STLs rendered
    for the three grip-angle test prints now that the printer arrived early.
    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
    [case.scad, grip_test_24deg.stl, grip_test_28deg.stl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]
2026-07-19 Case v0.2: sloped palm-rest base and flared grip root
    Reflects the real product's geometry pointed out in review: the base is
    a wedge (low at the wrist, high at the grip root) and the grip root
    flares out where the side of the palm heel rests. Regenerated the three
    grip-angle test STLs.
    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
    [case.scad, grip_test_24deg.stl, grip_test_28deg.stl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]
2026-07-20 Refresh next-actions: current status and recommended purchase sites
    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
